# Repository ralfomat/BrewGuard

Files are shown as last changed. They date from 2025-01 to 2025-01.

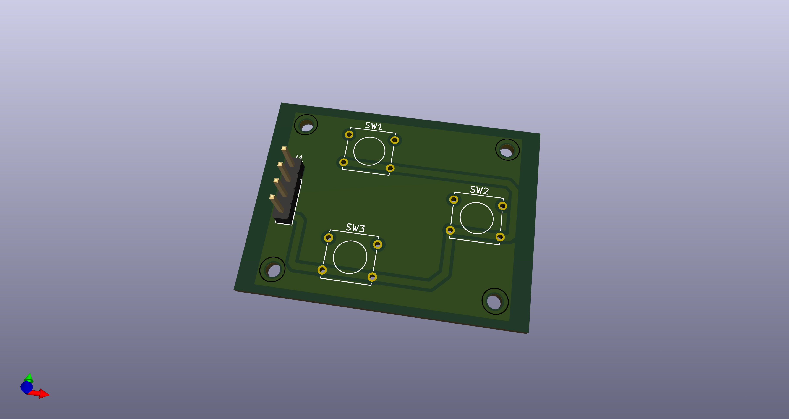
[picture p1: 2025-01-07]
BrewGuard PCB/Keyboard/keyboard.png

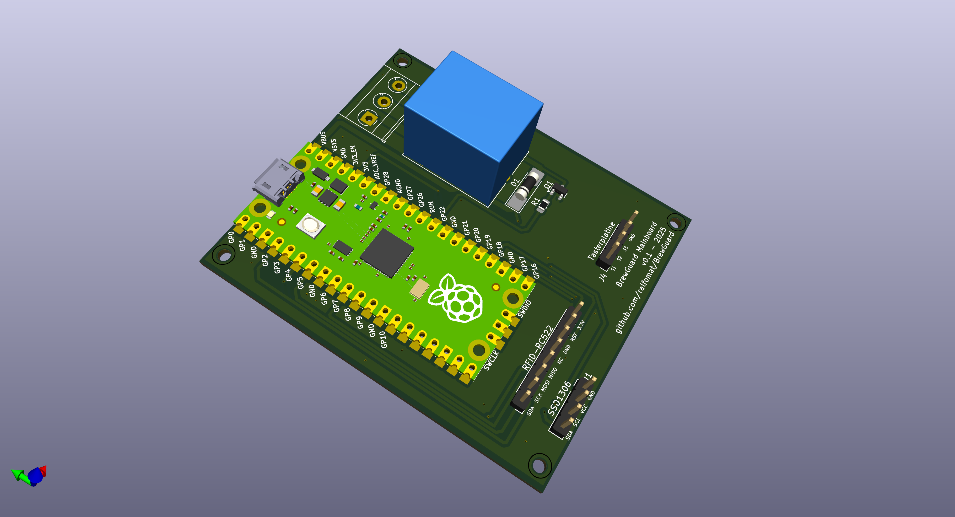
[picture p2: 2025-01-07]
BrewGuard PCB/CoffeGuard Mainboard/Coffee-Guard PCB.png

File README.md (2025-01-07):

## BrewGuard

BrewGuard is a Smart Coffee Access & Analytics System. A solution that transforms regular coffee machines into smart, trackable brewing stations using RFID authentication and real-time monitoring. This system combines hardware and software components to manage coffee machine access and track usage.

## Key Features

-   RFID-based authentication system for secure coffee machine access    
-   User permission management and access tracking
-   Support for multiple RFID tags and users
- User based tracking of coffee consumption

## Technical Stack

**Hardware**

-   RaspberryPi Pico based RFID reader integration
-   Coffee machine interface with Relay output
- 0.96" OLED Display
- Responsive UI

**Software**

-  Firmware written in MicroPython
-  PCBs designed in KICAD

This project is perfect for offices, shared workspaces, and environments where coffee consumption tracking and access control are essential.

## PCB Design

Coffee-Guard PCB
BrewGuard Mainboard v0.1

keyboard
BrewGuard Keyboard v0.1

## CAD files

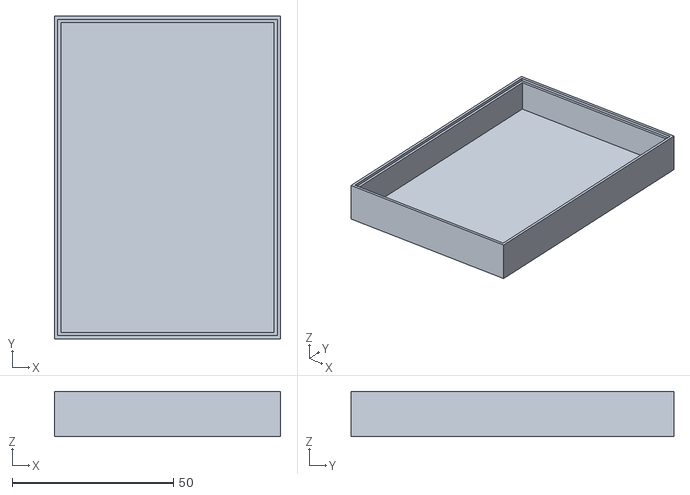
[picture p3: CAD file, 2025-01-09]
Housing/Housing lower part.stl
70.0 x 100.0 x 14.0

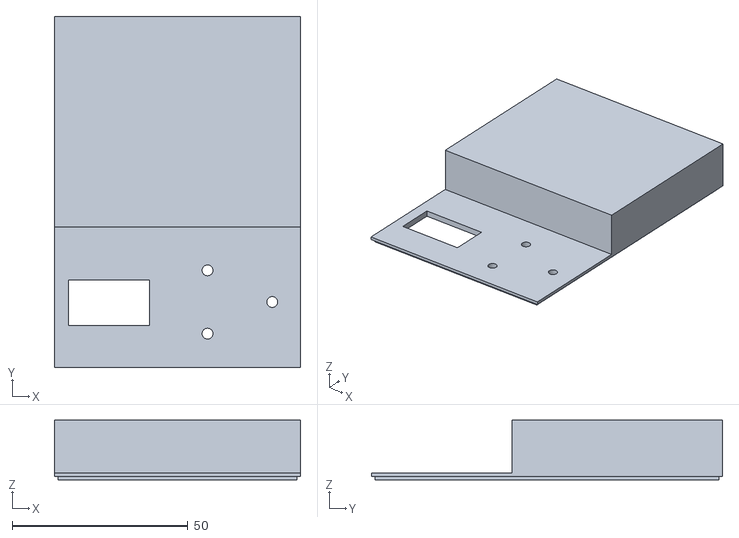
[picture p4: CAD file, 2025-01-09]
Housing/Housing upper part.stl
70.0 x 100.0 x 17.0

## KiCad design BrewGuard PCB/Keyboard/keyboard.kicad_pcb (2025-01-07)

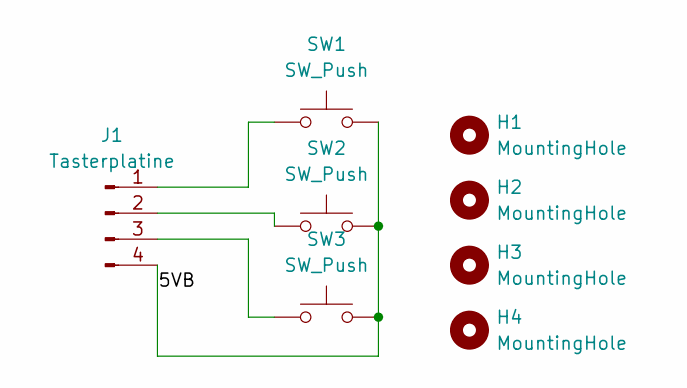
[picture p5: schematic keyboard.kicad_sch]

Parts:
H1, H2, H3, H4: MountingHole; MountingHole_2.2mm_M2_DIN965
J1: Tasterplatine; PinHeader_1x04_P2.54mm_Vertical
SW1, SW2, SW3: SW_Push; SW_Tactile_Straight_KSA0Axx1LFTR

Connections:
/5VB: J1.4, SW1.2, SW2.2, SW3.2
unnamed: J1.1, SW1.1
unnamed: J1.2, SW2.1
unnamed: J1.3, SW3.1

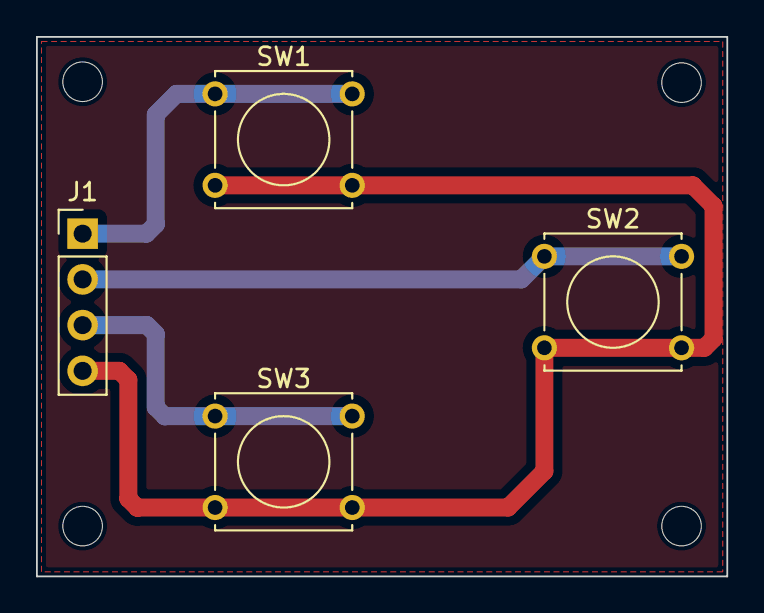
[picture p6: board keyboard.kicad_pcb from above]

Board: 2 copper layers, 38.4 x 30.0 mm, 8 parts (0 on the bottom side), 4 nets.

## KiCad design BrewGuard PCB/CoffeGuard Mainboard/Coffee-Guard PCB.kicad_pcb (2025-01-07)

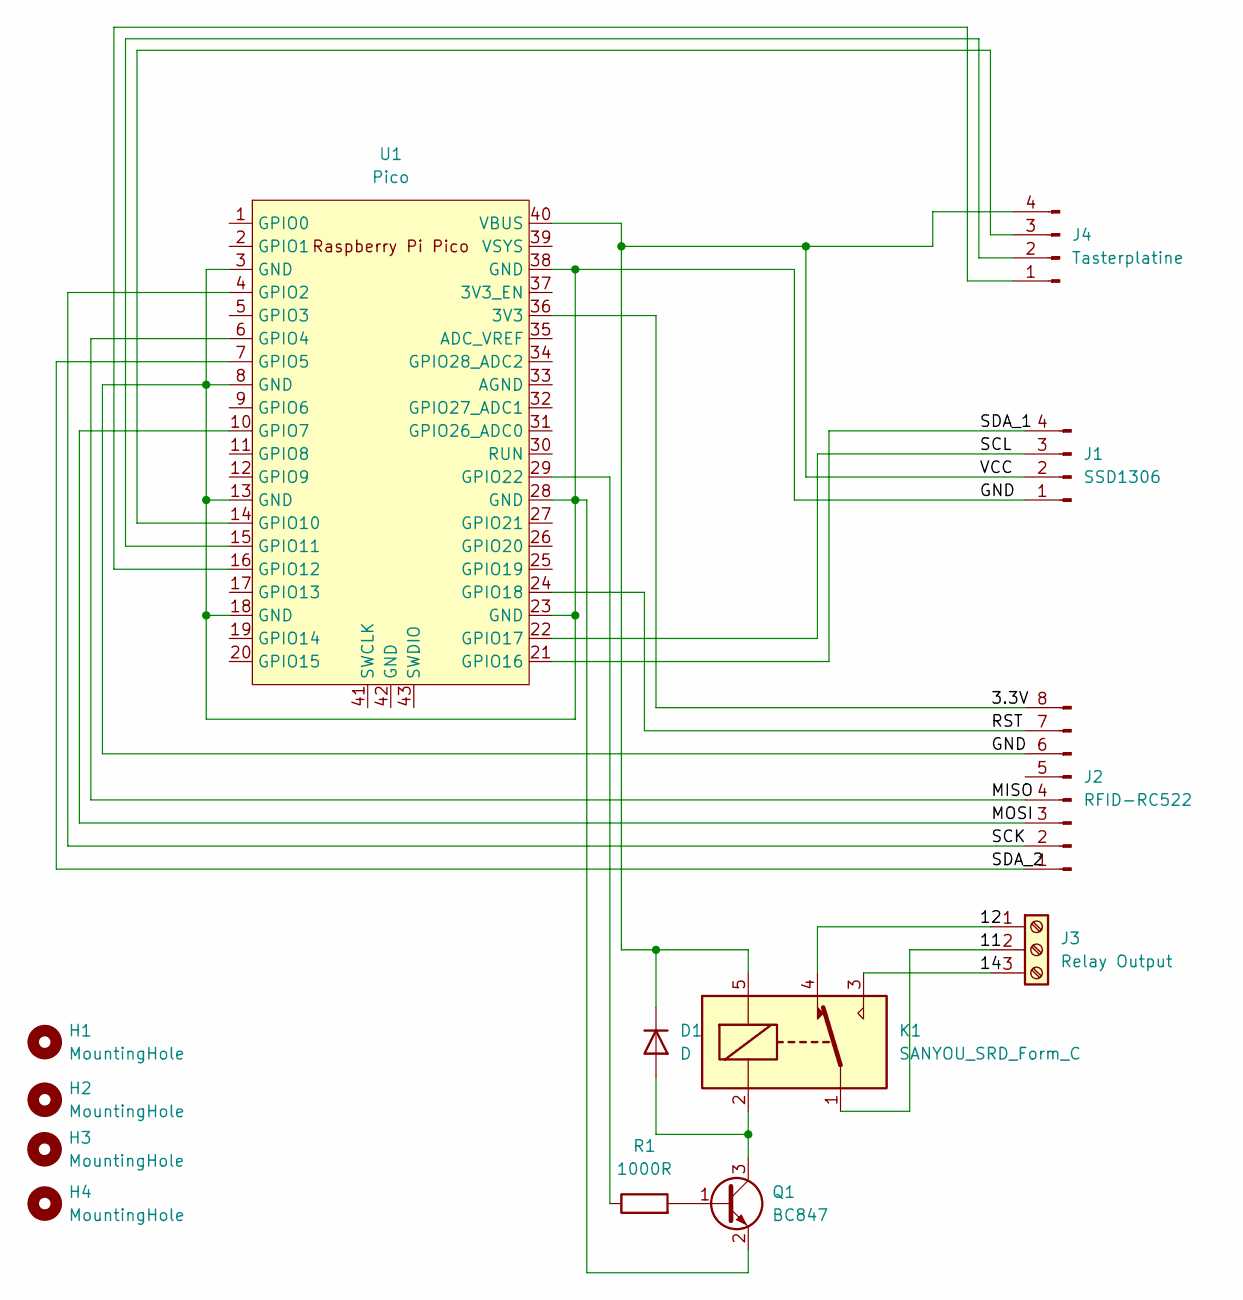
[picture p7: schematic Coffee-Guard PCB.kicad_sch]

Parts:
D1: D; D_MELF_Handsoldering
H1, H2, H3, H4: MountingHole; MountingHole_2.2mm_M2_DIN965
J1: SSD1306; PinHeader_1x04_P2.54mm_Vertical
J2: RFID-RC522; PinHeader_1x08_P2.54mm_Vertical
J3: Relay Output; TerminalBlock_MetzConnect_Type073_RT02603HBLU_1x03_P5.08mm_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
J4: Tasterplatine; PinHeader_1x04_P2.54mm_Vertical
K1: SANYOU_SRD_Form_C; Relay_SPDT_SANYOU_SRD_Series_Form_C
Q1: BC847; SOT-23
R1: 1000R; R_0805_2012Metric_Pad1.20x1.40mm_HandSolder
U1: Pico; RPi_Pico_SMD_TH

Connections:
/3.3V: J2.8, U1.36 (3V3)
/11: J3.2, K1.1
/12: J3.1, K1.4
/14: J3.3, K1.3
/GND: J1.1, J2.6, Q1.2 (E), U1.3 (GND), U1.8 (GND), U1.13 (GND), U1.18 (GND), U1.23 (GND), U1.28 (GND), U1.38 (GND)
/MISO: J2.4, U1.6 (GPIO4)
/MOSI: J2.3, U1.10 (GPIO7)
/RST: J2.7, U1.24 (GPIO18)
/SCK: J2.2, U1.4 (GPIO2)
/SCL: J1.3, U1.22 (GPIO17)
/SDA_1: J1.4, U1.21 (GPIO16)
/SDA_2: J2.1, U1.7 (GPIO5)
/VCC: D1.1 (K), J1.2, J4.4, K1.5, U1.40 (VBUS)
unnamed: D1.2 (A), K1.2, Q1.3 (C)
unnamed: J4.1, U1.16 (GPIO12)
unnamed: J4.2, U1.15 (GPIO11)
unnamed: J4.3, U1.14 (GPIO10)
unnamed: Q1.1 (B), R1.2
unnamed: R1.1, U1.29 (GPIO22)

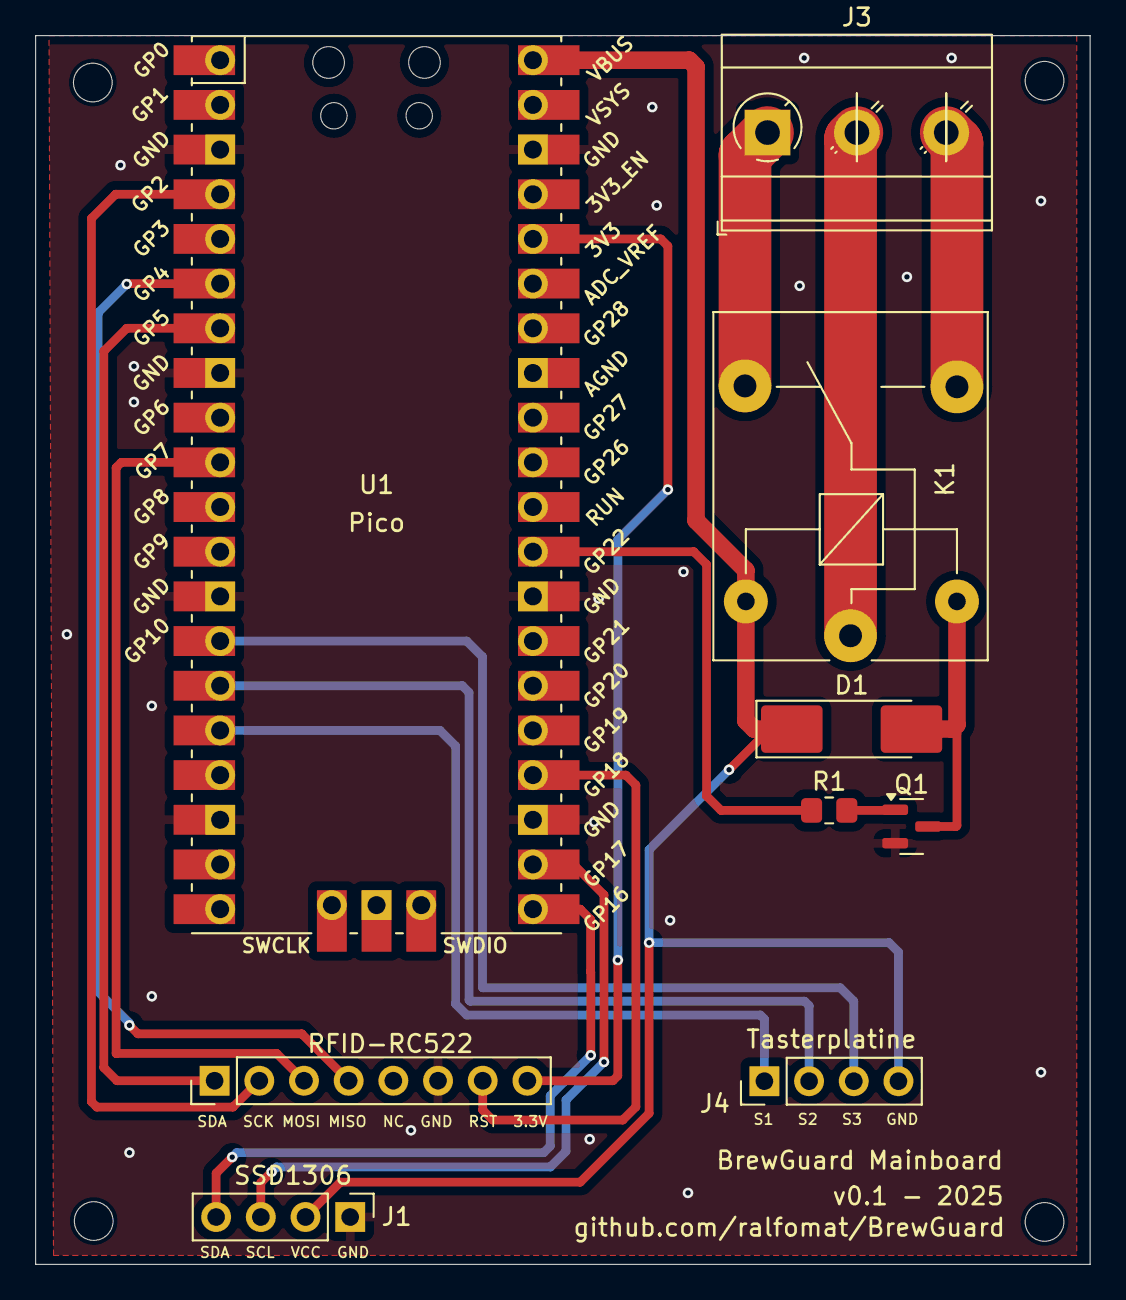
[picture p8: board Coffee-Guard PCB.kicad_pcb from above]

Board: 2 copper layers, 59.9 x 69.8 mm, 13 parts (0 on the bottom side), 19 nets.

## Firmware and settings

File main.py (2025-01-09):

import uasyncio as asyncio
from machine import Pin, I2C
from oled import Write, GFX, SSD1306_I2C
from oled.fonts import ubuntu_mono_15, ubuntu_mono_20, bookerly_20
from menu import Menu
from rfid_reader import RFIDReader
from user_manager import UserManager
import relay
import utime

# Konfiguration
CONFIG = {
    'WIDTH': 128,
    'HEIGHT': 64,
    'SCL_PIN': 17,
    'SDA_PIN': 16,
    'UP_PIN': 10,
    'DOWN_PIN': 11,
    'ENTER_PIN': 12,
    'RFID_SCK': 2,
    'RFID_MISO': 4,
    'RFID_MOSI': 7,
    'RFID_CS': 5,
    'RFID_RST': 18
}

def read_brew_time():
    try:
        with open('brew_time.txt', 'r') as file:
            brew_time = int(file.read().strip())
            return max(1, min(255, brew_time))
    except (FileNotFoundError, ValueError):
        return 30  # Standardwert, falls die Datei fehlt oder ungültig ist

def save_brew_time(new_brew_time):
    with open('brew_time.txt', 'w') as file:
        file.write(str(new_brew_time))

async def wait_for_rf_tag(rfid_reader, timeout=5000):  # timeout in Millisekunden
    start_time = utime.ticks_ms()
    while utime.ticks_diff(utime.ticks_ms(), start_time) < timeout:
        card_id = await rfid_reader.read_card()
        if card_id:
            return card_id
        await asyncio.sleep_ms(100)
    return None

last_button_press = {
    'up': 0,
    'down': 0,
    'enter': 0
}

DEBOUNCE_TIME = 250  

def debounce(pin):
    current_time = utime.ticks_ms()
    if utime.ticks_diff(current_time, last_button_press[pin]) > DEBOUNCE_TIME:
        last_button_press[pin] = current_time
        return True
    return False

async def button_pressed(buttons):
    button_names = ['up', 'down', 'enter']
    while True:
        for button, name in zip(buttons, button_names):
            if button.value():
                if debounce(name):
                    # Warte kurz und prüfe erneut, um sicherzustellen, dass es kein Prellen war
                    await asyncio.sleep_ms(50)
                    if button.value():
                        return button
        await asyncio.sleep_ms(10)

async def wait_for_button(buttons, timeout=5000):
    try:
        return await asyncio.wait_for(button_pressed(buttons), timeout / 1000)
    except asyncio.TimeoutError:
        return None

async def wait_for_new_tag(rfid_reader):
    while True:
        new_tag_id = await rfid_reader.read_card()
        if new_tag_id:
            return new_tag_id
        await asyncio.sleep_ms(100)

async def main():
    i2c = I2C(0, scl=Pin(CONFIG['SCL_PIN']), sda=Pin(CONFIG['SDA_PIN']), freq=400000)
    display = SSD1306_I2C(CONFIG['WIDTH'], CONFIG['HEIGHT'], i2c)
    
    menu = Menu(display)
    rfid_reader = RFIDReader(CONFIG)
    user_manager = UserManager()

    up = Pin(CONFIG['UP_PIN'], Pin.IN, Pin.PULL_DOWN)
    down = Pin(CONFIG['DOWN_PIN'], Pin.IN, Pin.PULL_DOWN)
    enter = Pin(CONFIG['ENTER_PIN'], Pin.IN, Pin.PULL_DOWN)

    current_menu = "main"
    selected_option = 0
    
    brew_time = read_brew_time()
    
    admin_menu_options = ["New User", "Reset User", "Show all Users", "Reset Counters", "Set Brew Time", "Back"]
    admin_menu_start = 0
    admin_menu_selected = 0

    while True:
        if current_menu == "main":
            menu.show_main_menu()
            card_id = await rfid_reader.read_card()
            
            if card_id:
                user = user_manager.get_user(card_id)
                if user:
                    if user.privileges == 'admin':
                        current_menu = "admin_main"
                    else:
                        current_menu = "user_main"
                else:
                    menu.show_incorrect_nfc()
                    await asyncio.sleep(2)
        
        elif current_menu == "admin_main":
            menu.show_admin_main_menu(selected_option, user.coffee_count)
            button = await wait_for_button([up, down, enter])
            
            if button is None:
                current_menu = "main"
                continue
            
            if button == up:
                selected_option = (selected_option - 1) % 2
            elif button == down:
                selected_option = (selected_option + 1) % 2
            elif button == enter:
                if selected_option == 0:  # Start
                    relay.relay_on()
                    user.increment_coffee_count()
                    menu.show_coffee_started(user.coffee_count)
                    await asyncio.sleep(brew_time)
                    relay.relay_off()
                    current_menu = "main"
                else:  # Admin
                    current_menu = "admin_menu"
                    selected_option = 0
        
        elif current_menu == "user_main":
            menu.show_user_main_menu(user.coffee_count)
            button = await wait_for_button([enter])
            
            if button is None:
                current_menu = "main"
                continue
            
            if button == enter:
                relay.relay_on()
                user.increment_coffee_count()
                menu.show_coffee_started(user.coffee_count)
                await asyncio.sleep(brew_time)
                relay.relay_off()
                current_menu = "main"
            
        elif current_menu == "admin_menu":
            menu.show_admin_menu(admin_menu_options, admin_menu_start, admin_menu_selected)
            button = await wait_for_button([up, down, enter])
            
            if button is None:
                current_menu = "main"
                continue
                        
            if button == up:
                admin_menu_selected = (admin_menu_selected - 1) % len(admin_menu_options)
                if admin_menu_selected < admin_menu_start:
                    admin_menu_start = admin_menu_selected
                elif admin_menu_selected >= admin_menu_start + 4:
                    admin_menu_start = admin_menu_selected - 3
            elif button == down:
                admin_menu_selected = (admin_menu_selected + 1) % len(admin_menu_options)
                if admin_menu_selected >= admin_menu_start + 4:
                    admin_menu_start = admin_menu_selected - 3
                elif admin_menu_selected < admin_menu_start:
                    admin_menu_start = admin_menu_selected
                    
            elif button == enter:
                if admin_menu_options[admin_menu_selected] == "New User":
                    menu.show_new_user_menu()
                    new_tag_id = await wait_for_new_tag(rfid_reader)
                    try:
                        result = user_manager.add_user(new_tag_id, 'user')
                        menu.show_user_added_success(new_tag_id)
                    except ValueError as e:
                        menu.show_user_exists_error(new_tag_id)
                    await asyncio.sleep(2)
                    
                elif admin_menu_options[admin_menu_selected] == "Reset User":
                    menu.show_rf_tag_prompt()
                    card_id = await wait_for_rf_tag(rfid_reader)
                    if card_id:
                        current_menu = "reset_counter"
                    else:
                        menu.show_timeout_message()
                        await asyncio.sleep(2)
                        current_menu = "admin_menu"
                
                elif admin_menu_options[admin_menu_selected] == "Show all Users":
                    current_menu = "show_all_users"
                    
                elif admin_menu_options[admin_menu_selected] == "Reset Counters":
                    current_menu = "reset_all_confirmation"
                
                elif admin_menu_options[admin_menu_selected] == "Set Brew Time":
                    current_menu = "set_time"
                
                elif admin_menu_options[admin_menu_selected] == "Back":
                    current_menu = "admin_main"
                    
            
        elif current_menu == "set_time":
            menu.show_set_time_menu(brew_time)
            button = await wait_for_button([up, down, enter])

            if button is None:
                current_menu = "admin_menu"
                continue

            if button == up:
                brew_time = min(255, brew_time + 1)
            elif button == down:
                brew_time = max(1, brew_time - 1)
            elif button == enter:
                save_brew_time(brew_time)
                current_menu = "admin_menu"
                
        elif current_menu == "reset_counter":
            user = user_manager.get_user(card_id)
            if user:
                selected_option = 0  # 0 für "Reset", 1 für "Back"
                while True:
                    menu.show_reset_counter_menu(user.coffee_count, selected_option)
                    button = await wait_for_button([up, down, enter])
                    
                    if button is None:
                        current_menu = "admin_menu"
                        break
                    elif button == up or button == down:
                        selected_option = 1 - selected_option  # Wechselt zwischen 0 und 1
                    elif button == enter:
                        if selected_option == 0:  # Reset
                            user.reset_coffee_count()
                            menu.show_reset_counter_menu(0, selected_option)
                            await asyncio.sleep(1)
                        current_menu = "admin_menu"
                        break
            else:
                menu.show_incorrect_nfc()
                await asyncio.sleep(2)
                current_menu = "admin_menu"
                
                await asyncio.sleep_ms(100)
        
        elif current_menu == "show_all_users":
            users = list(user_manager.users.values())
            start_index = 0
            while True:
                menu.show_all_users(users, start_index)
                button = await wait_for_button([up, down, enter])
                if button == up and start_index > 0:
                    start_index -= 1
                elif button == down and start_index < len(users) - 4:
                    start_index += 1
                elif button == enter:
                    current_menu = "admin_menu"
                    break

        elif current_menu == "reset_all_confirmation":
            selected_option = 0
            while True:
                menu.show_reset_all_confirmation(selected_option)
                button = await wait_for_button([up, down, enter])
                if button == up or button == down:
                    selected_option = 1 - selected_option
                elif button == enter:
                    if selected_option == 0:  # Back
                        current_menu = "admin_menu"
                    else:  # OK
                        for user in user_manager.users.values():
                            user.reset_coffee_count()
                        user_manager.save_users()
                        menu.show_counter_reset()
                        await asyncio.sleep(2)
                        current_menu = "admin_menu"
                    break
        

if __name__ == "__main__":
    asyncio.run(main())

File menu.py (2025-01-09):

from oled import Write, GFX, SSD1306_I2C
from oled.fonts import ubuntu_mono_15, ubuntu_mono_20, bookerly_20

class Menu:
    def __init__(self, display):
        self.display = display
        self.gfx = GFX(display.width, display.height, display.pixel)
        self.write20 = Write(display, bookerly_20)

    def show_main_menu(self):
        self.display.fill(0)
        self.write20.text("BrewGuard", 10, 0)
        self.display.text("Waiting for", 15, 32)
        self.display.text("your RF-TAG", 10, 42)
        self.display.show()

    def show_admin_main_menu(self, selected_option, coffee_count):
        self.display.fill(0)
        self.write20.text("BrewGuard", 10, 0)
        self.display.text(f"Coffees: {coffee_count}", 0, 32)
        self.display.text("Start", 4, 52)
        self.display.text("Admin", 85, 52)
        if selected_option == 0:
            self.gfx.rect(0, 49, 50, 14, 1)
        else:
            self.gfx.rect(80, 49, 50, 14, 1)
        self.display.show()

    def show_user_main_menu(self, coffee_count):
        self.display.fill(0)
        self.write20.text("BrewGuard", 10, 0)
        self.display.text(f"Coffees: {coffee_count}", 0, 32)
        self.gfx.rect(0, 49, 50, 14, 1)
        self.display.text("Start", 4, 52)
        self.display.show()

    def show_incorrect_nfc(self):
        self.display.fill(0)
        self.write20.text("BrewGuard", 10, 0)
        self.display.text("User not", 28, 32)
        self.display.text("recognized!", 18, 42)
        self.display.show()

    def show_admin_menu(self, options, start_index, selected_index):
        self.display.fill(0)
        self.display.text("Admin Menu", 0, 0)
        for i in range(4):
            if start_index + i < len(options):
                self.display.text(options[start_index + i], 5, 16 + i * 12)
        selected_y = 14 + ((selected_index - start_index) % 4) * 12
        self.gfx.rect(0, selected_y, 128, 12, 1)
        self.display.show()

    def show_coffee_started(self, coffee_count):
        self.display.fill(0)
        self.display.text("Coffee", 30, 10)
        self.display.text("Started!", 25, 25)
        self.display.text(f"Coffee No. {coffee_count}", 20, 40)
        self.display.show()
        
    def show_new_user_menu(self):
        self.display.fill(0)
        self.display.text("Show new RF-TAG", 0, 20)
        self.display.show()

    def show_new_user_registered(self):
        self.display.fill(0)
        self.display.text("New User", 30, 20)
        self.display.text("registered", 20, 40)
        self.display.show()
        
    def show_set_time_menu(self, brew_time):
        self.display.fill(0)
        self.display.text("Set Brew Time", 0, 0)
        self.display.text(f"Time: {brew_time}s", 20, 30)
        self.gfx.rect(80, 50, 40, 14, 1)
        self.display.text("Save", 85, 53)
        self.display.show()
        
    def show_rf_tag_prompt(self):
        self.display.fill(0)
        self.display.text("Show RF-Tag", 10, 20)
        self.display.text("Waiting...", 20, 40)
        self.display.show()

    def show_reset_counter_menu(self, coffee_count, selected_option):
        self.display.fill(0)
        self.display.text(f"Count: {coffee_count}", 20, 20)
        self.display.text("Reset", 5, 53)
        self.display.text("Back", 93, 53)
        if selected_option == 0:
            self.gfx.rect(0, 50, 50, 14, 1)
        else:
            self.gfx.rect(88, 50, 40, 14, 1)
        self.display.show()
        
    def show_timeout_message(self):
        self.display.fill(0)
        self.display.text("Timeout", 30, 20)
        self.display.text("No RF-TAG detected", 0, 40)
        self.display.show()
        
    def show_user_exists_error(self, user_id):
        self.display.fill(0)
        self.display.text("Error:", 0, 10)
        self.display.text(f"User ID {user_id}", 0, 30)
        self.display.text("already exists", 0, 40)
        self.display.show()

    def show_user_added_success(self, user_id):
        self.display.fill(0)
        self.display.text("Success:", 0, 10)
        self.display.text(f"User ID {user_id}", 0, 30)
        self.display.text("added", 0, 40)
        self.display.show()

    def show_all_users(self, users, start_index):
        self.display.fill(0)
        self.display.text("Users:", 0, 0)
        for i in range(4):
            if start_index + i < len(users):
                user = users[start_index + i]
                self.display.text(f"{user.rf_id}: {user.coffee_count}", 0, 16 + i * 12)
        self.display.show()

    def show_reset_all_confirmation(self, selected_option):
        self.display.fill(0)
        self.display.text("Reset all User", 0, 10)
        self.display.text("Counters?", 0, 22)
        self.display.text("Back", 9, 52)
        self.display.text("OK", 102, 52)
        if selected_option == 0:
            self.gfx.rect(5, 48, 40, 16, 1)
        else:
            self.gfx.rect(95, 48, 30, 16, 1)
        self.display.show()
        
    def show_counter_reset(self):
        self.display.fill(0)
        self.display.text("All counters", 0, 20)
        self.display.text("are reset!", 0, 40)
        self.display.show()
        
    def show_message(self, message):
        self.display.fill(0)
        lines = message.split('\n')
        for i, line in enumerate(lines):
            self.display.text(line, 0, i * 12)
        self.display.show()

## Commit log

2025-01-07 pcb files
    [Coffee-Guard PCB.kicad_pcb, Coffee-Guard PCB.kicad_sch, freerouting.dsn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]
2025-01-09 add additional options for admin menu
    [Housing lower part.stl, Housing upper part.stl]
